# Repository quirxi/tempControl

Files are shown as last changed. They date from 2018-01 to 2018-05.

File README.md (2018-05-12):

# **Temperature Control**

A basic temperature control example that reads in a temperature via a K-Type thermocouple sensor.
The volt output of the sensor is processed by an MAX31855 board and read out by an Arduino Nano.
The so gained temperature value is given out to the serial console of the Arduino Nano.
On an output pin of the arduino nano a Solid State Relay (SSR) is connected. 
A PID controller is switching the SSR till the given target temperature is reached.

## Instructions

### What you need:

* [Thermocouple](https://www.banggood.com/de/Universal-K-Type-EGT-Thermocouple-Temperature-Sensors-For-Exhaust-Gas-Probe-p-1011377.html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)
* [MAX31855 K-Type thermoelement breakout board for arduino](https://www.banggood.com/de/MAX31855-K-Type-Thermocouple-Breakout-Board-Temperature-Measurement-Module-For-Arduino-p-1086523.html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)
* [Arduino Nano clone](https://www.banggood.com/de/ATmega328P-Arduino-Compatible-Nano-V3-Improved-Version-No-Cable-p-959231.html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)
* [Solid State Relay](https://www.banggood.com/80A-SSR-80DA-Solid-State-Relay-Module-DC-To-AC-24V-380V-Output-p-1097188.html)
* you will also need a soldering iron, jumper cables, breadbord etc.

### Setup

__Hardware__

1. Resolder the plug onto the other side of the MAX31855K breakout board, so that it can be easily attach it to the breadboard.

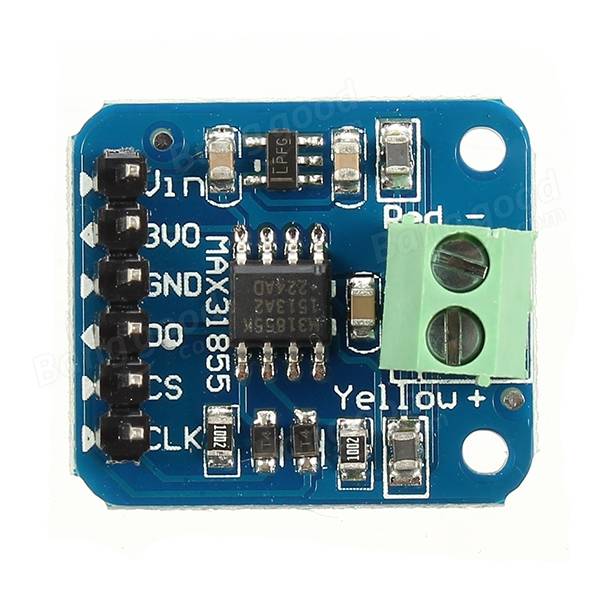
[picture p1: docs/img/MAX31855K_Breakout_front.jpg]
Original MAX31855K breakout board front

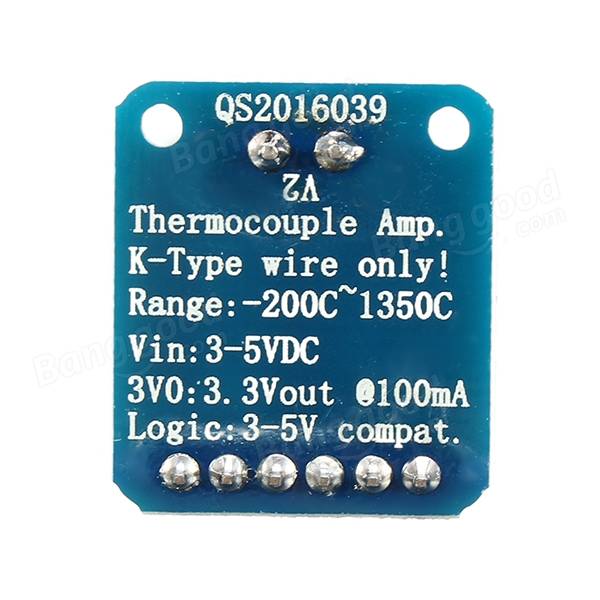
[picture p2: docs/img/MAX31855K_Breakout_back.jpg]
Original MAX31855K breakout board back

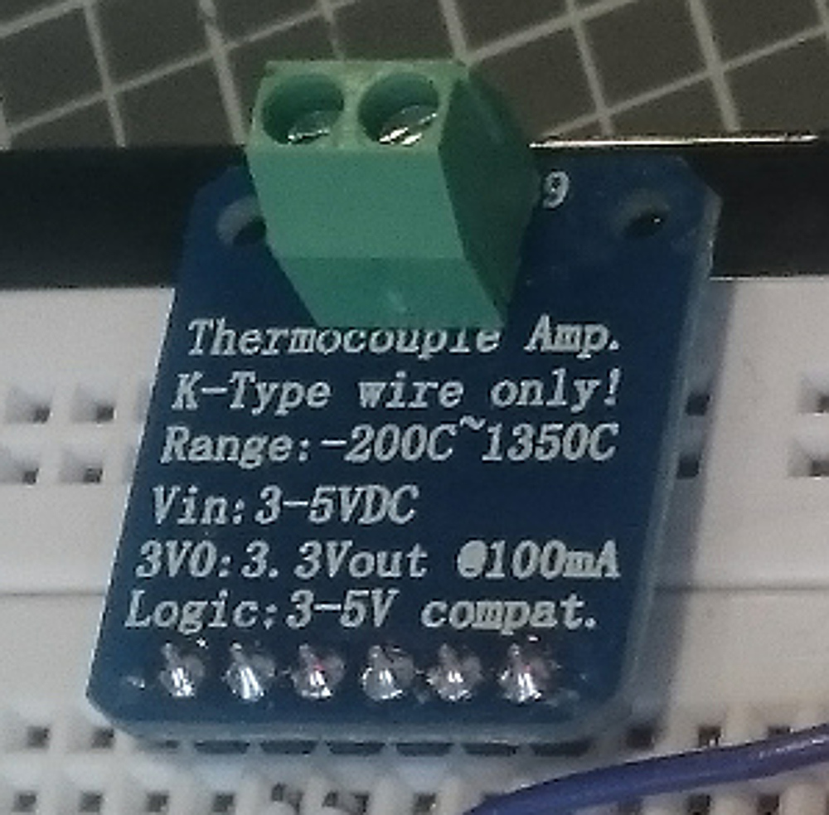
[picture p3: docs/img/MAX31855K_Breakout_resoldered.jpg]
MAX31855K breakout board resoldered


2. Connect the Arduino nano with the MAX31855K breakout board according to following circuit diagram.

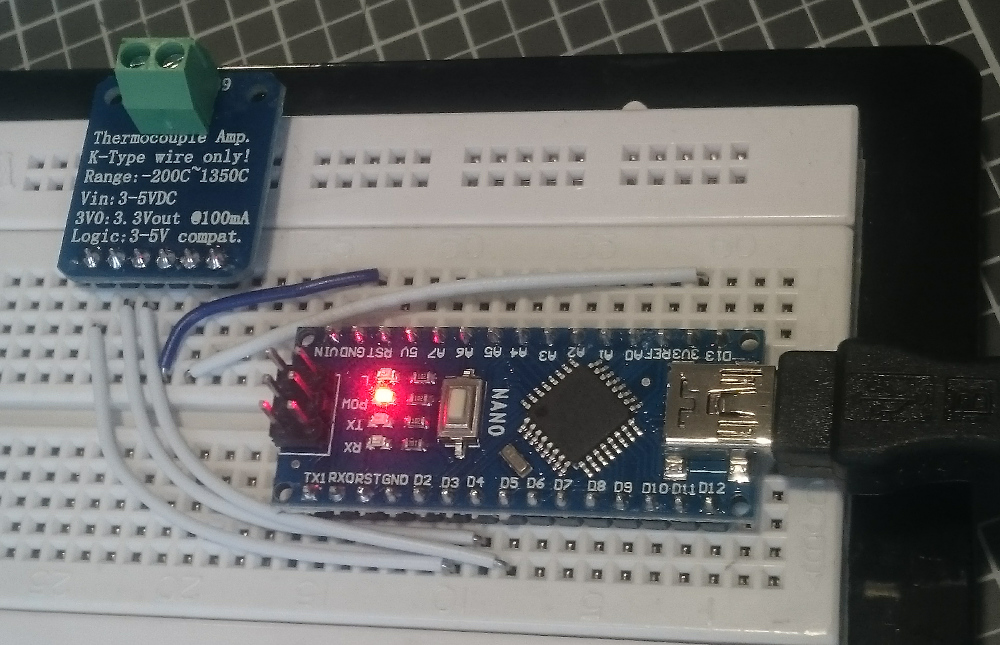
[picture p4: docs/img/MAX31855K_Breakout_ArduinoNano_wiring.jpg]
Breadboard wiring

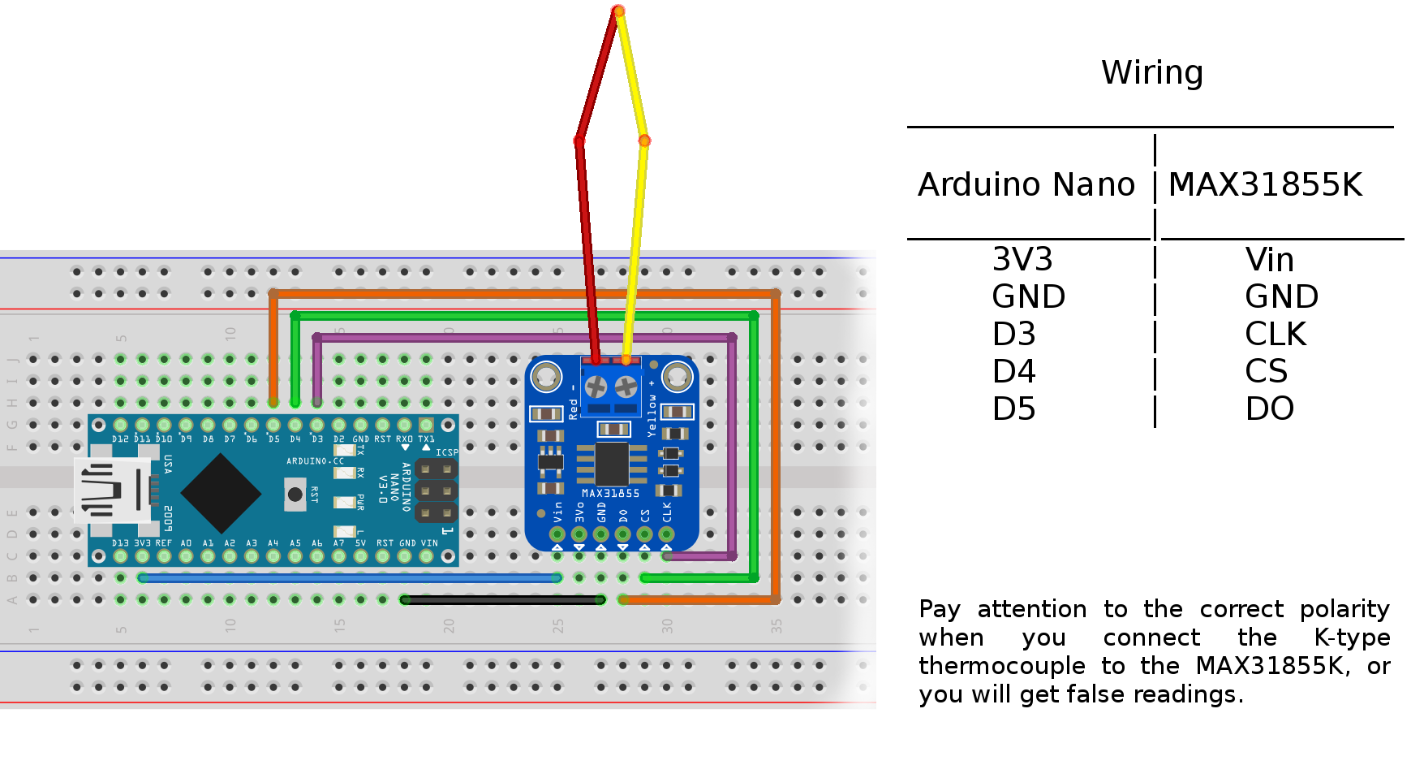
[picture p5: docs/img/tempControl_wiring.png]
Wiring diagram


* You can find the Fritzing wiring diagram file (tempControl.fzz) in the docs folder.

__Software__

1. Download and install the newest Arduino IDE from https://www.arduino.cc/en/Main/Software. 

2. If you need help using Arduino have a look at www.arduino.cc/en/Guide/HomePage. 
    
3. Install the newest Arduino IDE from https://www.arduino.cc/en/main/software (version 1.8.5 at time of writing). 
    
4. Open "Menu->Sketch->Include Libraries->Manage Libraries.." in the Arduino IDE and search for "Adafruit MAX31855" and "PID" by Brett Beauregard (version 1.2.0 at time of writing) and install it. 

### Programming

1. Open the "tempControl.ino" file that you can find here, "Verify" and "Upload" it to your Arduino board via USB connection
    
2. Once the code upload finishes verifying, open the serial monitor (found in the ‘Tools’ menu). You should be able to read the temperature your thermocouple is detecting on the serial monitor in real time. If it isn’t working, make sure you have assembled the circuit and uploaded the code to your board correctly. 

### Explanation

__1. K Type Thermocouple__

A thermocouple is a kind of temperature sensor, simply made by welding together two metal wires. Because of a physical effect of two joined metals, there is a slight but measurable voltage across the wires that increases with temperature (Seebeck-Effekt). The main advantage of using a thermocouple is the high temperature range (our K type: -200°C to 1200°C). A difficulty in using them is that the voltage to be measured is very small, with changes of about 50 uV per °C. To solve this we are using a thermocouple interface chip (MAX31855K) to measure the voltage between the wires. If you find that the thermocouple temperature goes down instead of up when heated, when connecting the K type thermocouples with the MAX31855K, try swapping the red and yellow wires.

__2. MAX31855K__

The MAX31855K is a chip that converts the voltage output of the thermocouple to a digital temperature value that is read out via SPI 
protocol. The first assembly step is creating a reliable, electrical connection from the MAX31855K breakout board to your Arduino. We chose 
to use a breakout board because we wanted to connect it to a bread board. The hookup is fairly straightforward. Connect the Arduino, MAX31855K and thermocouple as described in the Fritzing wiring diagram.

__3. Arduino nano__

The Arduino nano communicates with the MAX31855K through SPI protocol. For further details see next point.

__4. SPI protocol__

The SPI is a fast synchronous protocol that tipically uses uses 4 pins for communication, wiz. MISO, MOSI, SCK, and SS. These pins are directly related to the SPI bus interface.

    1. MISO – MISO stands for Master In Slave Out. MISO is the input pin for Master AVR, and output pin for Slave AVR device. Data transfer from Slave to Master takes place through this channel.
    2. MOSI – MOSI stands for Master Out Slave In. This pin is the output pin for Master and input pin for Slave. Data transfer from Master to Slave takes place through this channel.
    3. SCK – This is the SPI clock line (since SPI is a synchronous communication).
    4. SS – This stands for Slave Select. This pin would be discussed in detail later in the post.
    
__5. PID controller__

PID Controller is a most common control algorithm used in industrial automation & applications. PID controllers are used for precise and accurate control of various parameters. Most often these are used for the regulation of temperature, pressure, speed, flow and other process variables. For in depth information about how PID controller work see reference section.

## License

Distributed under the GNU LGPL v.3.0.

## References

* [Thermocouple](https://www.banggood.com/de/Universal-K-Type-EGT-Thermocouple-Temperature-Sensors-For-Exhaust-Gas-Probe-p-1011377.html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)
* [MAX31855 K-Type thermoelement breakout board for arduino](https://www.banggood.com/de/MAX31855-K-Type-Thermocouple-Breakout-Board-Temperature-Measurement-Module-For-Arduino-p-1086523.html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)
* [Arduino Nano clone](https://www.banggood.com/de/ATmega328P-Arduino-Compatible-Nano-V3-Improved-Version-No-Cable-p-959231.html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)
* [Solid State Relay](https://www.banggood.com/80A-SSR-80DA-Solid-State-Relay-Module-DC-To-AC-24V-380V-Output-p-1097188.html)
* [henrysbench arduino-max31855 tutorial](http://henrysbench.capnfatz.com/henrys-bench/arduino-temperature-measurements/max31855-arduino-k-thermocouple-sensor-manual-and-tutorial/)
* [MAX31855 specs and datasheet](https://datasheets.maximintegrated.com/en/ds/MAX31855.pdf)
* [ATmega328 Datasheet](http://www.atmel.com/Images/Atmel-42735-8-bit-AVR-Microcontroller-ATmega328-328P_Datasheet.pdf)
* [Arduino Nano Pinout Diagram](http://www.pighixxx.com/test/wp-content/uploads/2014/11/nano.png)
* [Arduino Anleitung](www.arduino.cc/en/Guide/HomePage)
* [K-Type Thermocouple specs](https://www.thermocoupleinfo.com/type-k-thermocouple.htm)
* [PID diagrams](http://ww1.microchip.com/downloads/en/AppNotes/Atmel-2558-Discrete-PID-Controller-on-tinyAVR-and-megaAVR_ApplicationNote_AVR221.pdf)
* [Working of a PID controller](https://www.elprocus.com/the-working-of-a-pid-controller/)
* [PID controller](http://manuals.chudov.com/Servo-Tuning/PID-without-a-PhD.pdf)
* [PID controlling algorithm](http://brettbeauregard.com/blog/2011/04/improving-the-beginners-pid-introduction/)
* [PID Arduino library](https://github.com/br3ttb/Arduino-PID-Library)
* [PID for dummies](https://www.csimn.com/CSI_pages/PIDforDummies.html)

## TODOs

* Solid State Relais
* GUI
* [PID tuning](https://en.wikipedia.org/wiki/Ziegler%E2%80%93Nichols_method)
* Change Fritzing pictures and table for hardware SPI.
* Pictures of new setpup with water kettle

## Authors

* quirxi (https://github.com/quirxi)
* Cubemast3r (https://github.com/Cubemast3r)

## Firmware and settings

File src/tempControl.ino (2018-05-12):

/*
   This program uses interrupts for (longer) timing tasks in the seconds range.

   @see: http://brettbeauregard.com/blog/2011/04/improving-the-beginner%e2%80%99s-pid-sample-time/
   @see: https://arduino-projekte.webnode.at/registerprogrammierung/timer-interrupt/
   @see: http://www.gammon.com.au/interrupts
   @see: http://www.gammon.com.au/timers
   @see: http://www.instructables.com/id/Arduino-Timer-Interrupts/
   @see: http://maxembedded.com/2011/07/avr-timers-ctc-mode/
 * */
////////////////////////////////////////////////////////////////////////////////////////////
// MAX31855 k-type thermocouple:
//                creating a thermocouple instance with hardware SPI on a given CS pin.
////////////////////////////////////////////////////////////////////////////////////////////
#include "Adafruit_MAX31855.h"
#define MAXCS   10
Adafruit_MAX31855 thermocouple(MAXCS);

////////////////////////////////////////////////////////////////////////////////////////////
// PID
////////////////////////////////////////////////////////////////////////////////////////////
#include "PIDcontrol.h"

// set the pins for input, output and sample frequency here:
const unsigned short PID_INPUT_PIN = 0; // pin from which sensor input is read
const unsigned short PID_RELAY_PIN = 5; // pin that is used to control relay

// specify the PID constants here:
double cProportional = 1000;            // the proportional constant
double cIntegral = 0;                   // the integral constant
double cDerivative = 0;                 // the derivative constant

double pidSetpoint;                     // the desired target setpoint
volatile double pidInput;               // the input to the PID controller as read from the sensor (=PID_INPUT_PIN)
volatile double pidLastInput;           // the last input to be remembered in case the current reading is NAN (Not a Number) and cannot be used for computation.
volatile double pidOutput;              // specifies how long the relay is switched on within a fixed period of time (=sampleInterval)
unsigned short  sampleInterval;         // a fixed period of time that determines a full PID on/off cycle (ms) ATTENTION: sampleInterval [ms] is the same as INTERRUPT_INTERVAL[s] and cannot be greater than 4.1944 seconds
volatile bool   errorReading;           // is set when temperature reading returned NAN
// initialize the PID controller
PIDcontrol myPID(&pidInput, &pidOutput, &pidSetpoint, cProportional, cIntegral, cDerivative, DIRECT);

////////////////////////////////////////////////////////////////////////////////////////////
// INTERRUPT
////////////////////////////////////////////////////////////////////////////////////////////

// ATTENTION: Here TIMER 1 is used which is a 16-bit timer. Thus the compare value cannot be greater than 65535, otherwise the timer would overflow.
//            So the maximum time between two interrupts with a cpu frequency of 16000000 hz can only be:
//                OCR1A = CMP_VALUE = INTERRUPT_INTERVAL * TICKS_PER_SEC - 1
//                => INTERRUPT_INTERVAL = CMP_VALUE / (TICKS_PER_SEC - 1)
//                => INTERRUPT_INTERVAL = CMP_VALUE / (( CPU_FREQ / PRESCALER ) - 1)
//                => INTERRUPT_INTERVAL = 65535 / (( 16000000 / 1024 ) - 1)
//                => INTERRUPT_INTERVAL = 4.1945 seconds

#define CPU_FREQ 16000000L    // cpu clock from boards.txt
#define PRESCALER 1024        // cpu prescaler

// NOTE: we use seconds here as a basis because when using miliseconds the precision of the number would be inexact due to floating point calculations.
const unsigned short TICKS_PER_SEC = ( CPU_FREQ / PRESCALER );            // base for calculation of compare value for output compare register OCR1A
const unsigned short INTERRUPT_INTERVAL = 4;                              // interrupt every 4 seconds (=maximum interrupt intervall and maximum sample pid sample time)
const unsigned short CMP_VALUE = INTERRUPT_INTERVAL * TICKS_PER_SEC - 1;  // compare value for OCR1A: = amount of ticks in an interrupt intervall
const unsigned short MAX_CMP_VALUE = 65535 - 1;                           // maximum number in a 16-bit variable

volatile unsigned long counter = 0;
volatile unsigned long cntCmp = 0;

////////////////////////////////////////////////////////////////////////////////////////////
// SETUP
////////////////////////////////////////////////////////////////////////////////////////////
void setup()
{
    // MAX31555 thermocouple and serial initialization
    Serial.begin(9600);
    while (!Serial) delay(1);           // wait for serial on Leonardo/Zero, etc
    delay(500);                         // wait for MAX chip to stabilize
    // SSR initialization
    pinMode(PID_RELAY_PIN, OUTPUT);     // set the relay pin to output
    digitalWrite(PID_RELAY_PIN, LOW);   // initialize relay pin to low
    //PID
    pinMode(PID_RELAY_PIN, OUTPUT);              // set the relay pin to output
    digitalWrite(PID_RELAY_PIN, LOW);            // initialize relay pin to low
    pidSetpoint = 55;                            // set the desired target value
    sampleInterval = INTERRUPT_INTERVAL * 1000;  // the sample time of the pid controller is the interrupt frequency in miliseconds
    myPID.SetSampleTime(sampleInterval);         // tell the PID controller how frequently we will read a sample and calculate output
    myPID.SetOutputLimits(0, sampleInterval);    // tell the PID to range between 0 and the full window size
    myPID.SetMode(AUTOMATIC);                    // turn the PID on
    pidInput = thermocouple.readCelsius();       // read temperature sensor input
    myPID.Compute();                             // compute pidOutput for the first time

    Serial.print("CPU_FREQ:            ");
    Serial.println(CPU_FREQ);
    Serial.print("PRESCALER:           ");
    Serial.println(PRESCALER);
    Serial.print("TICKS_PER_SEC:       ");
    Serial.println(TICKS_PER_SEC);
    Serial.print("CMP_VALUE:           ");
    Serial.println(CMP_VALUE);
    Serial.print("MAX_CMP_VALUE:       ");
    Serial.println(MAX_CMP_VALUE);
    Serial.print("INTERRUPT_INTERVAL: ");
    Serial.println(INTERRUPT_INTERVAL);

    Serial.print("sampleInterval: ");
    Serial.print(sampleInterval);
    Serial.print(" | Setpoint: ");
    Serial.print(pidSetpoint);
    Serial.print(" | P: ");
    Serial.print(cProportional);
    Serial.print(" I: ");
    Serial.print(cIntegral);
    Serial.print(" D: ");
    Serial.println(cDerivative);

    // INTERRUPTS
    cli();                               // disable global interrupts
    TCNT1 = 0;                           // delete timer counter register
    TCCR1A = 0;                          // delete TCCR1A-Registers
    TCCR1B = 0;                          // delete TCCR1B-Registers
    TCCR1B |= (1 << WGM12);              // CTC-Mode (Waveform Generation Mode): resets TCNT1 to0 after interrupt, makes OCR1A the leading compare register
    TCCR1B |= (1 << CS12) | (1 << CS10); // set prescaler to 1024: CS10 und CS12 (Clock Select)
    OCR1A = CMP_VALUE;                   // set compare value
    OCR1B = MAX_CMP_VALUE;               // a second comapare value in OCR1B can be used as long as its value is *lower* than that of OCR1A: here its higher so it wont be called in the beginning
    TIMSK1 |= (1 << OCIE1A) | (1 << OCIE1B); // enable interrupts: set output compare interrupt enable for 1A and 1B
    sei();                               // enable global interrupts
}

////////////////////////////////////////////////////////////////////////////////////////////
// INTERRUPTS
////////////////////////////////////////////////////////////////////////////////////////////
ISR(TIMER1_COMPA_vect)   // Interrupt Service Routine for timer 1 OCR1A
{
    pidInput = thermocouple.readCelsius(); // read temperature sensor input
    if (!isnan(pidInput)) pidLastInput = pidInput;
    else
    {
        pidInput = pidLastInput;
        errorReading = true;
    }
    myPID.Compute();                       // compute pidOutput

    if (pidOutput > 0)
        digitalWrite(PID_RELAY_PIN, HIGH);
    else
        digitalWrite(PID_RELAY_PIN, LOW);

    // trigger interrupt b to turn off relay within the sample time (=sampleInterval)
    if ( pidOutput > 0 && pidOutput < sampleInterval )
        OCR1B = ((pidOutput * TICKS_PER_SEC) / 1000) - 1;
    else
        OCR1B = MAX_CMP_VALUE;    // we set OCR1B higher than OCR1A so that the second b interrupt never gets called

    ++counter;                    // flag that signals the start of a new cycle to the main loop
}

// Interrupt Service Routine for timer 1 OCR1B
ISR(TIMER1_COMPB_vect)
{
    digitalWrite(PID_RELAY_PIN, LOW);
}

////////////////////////////////////////////////////////////////////////////////////////////
// MAIN LOOP
////////////////////////////////////////////////////////////////////////////////////////////
void loop()
{
    if (cntCmp != counter)    // use != for comparison and not < because it could give problems when unsigned long overflows
    {
        Serial.print(counter);
        Serial.print(": ");
        Serial.print(millis());
        if (errorReading)   // for error codes see: https://cdn-shop.adafruit.com/datasheets/MAX31855.pdf#page=10 
        {
            Serial.print(":\tERROR: ");
            uint8_t errorCode = thermocouple.readError();
            switch( errorCode )
            {
            case 1:
                Serial.println("(1) Thermocouple has no connection (open circuit)!");
                break;
            case 2:
                Serial.println("(2) Thermocouple short-circuited to GND!");
                break;
            case 4:
                Serial.println("(4) Thermocouple short-circuited to VCC!");
                break;
            default:
                Serial.print("(");
                Serial.print(errorCode);
                Serial.println(") Unkown error code!");
            }
            errorReading=false;    // IMPORTANT: reset error flag !!
        }
        else
        {
            Serial.print(":\tpidInput: ");
            Serial.print( pidInput);
            Serial.print(" | pidOutput: ");
            Serial.print(pidOutput);
            Serial.print(" | OCR1A: ");
            Serial.print(OCR1A);
            Serial.print(" | OCR1B: ");
            Serial.println(OCR1B);
        }
        cntCmp = counter;
    }
}

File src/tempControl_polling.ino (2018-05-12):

#include "Adafruit_MAX31855.h"
#include <PID_v1.h>

// @TODO: Error handling when readCelsius returns NAN

// set the pins for input, output and sample frequency here:
//const unsigned short PID_INPUT_PIN = 0; // pin from which sensor input is read
const unsigned short PID_RELAY_PIN = 5; // pin that is used to control relay
const unsigned int PID_CYCLE = 4000;    // a fixed period of time that determines a full PID on/off cycle (ms)

// specify the PID constants here:
double cProportional = 1000;          // the proportional constant
double cIntegral = 0;                 // the integral constant
double cDerivative = 0;               // the derivative constant

double pidSetpoint;                     // the desired target setpoint
double pidInput;                        // the input to the PID controller as read from the sensor (=PID_INPUT_PIN)
double pidOutput;                       // specifies how long the relay is switched on within a fixed period of time (=PID_CYCLE)
unsigned long pidStart;                 // variable that marks the start of each PID_CYCLE
// initialize the PID controller
PID myPID(&pidInput, &pidOutput, &pidSetpoint, cProportional, cIntegral, cDerivative, DIRECT);


// creating a thermocouple instance with hardware SPI on a given CS pin.
#define MAXCS   10
Adafruit_MAX31855 thermocouple(MAXCS);


////////////////////////////////////////////////////////////////////////////////
//
////////////////////////////////////////////////////////////////////////////////
void setup()
{
  // MAX31555 thermocouple and serial initialization
  Serial.begin(9600);
  while (!Serial) delay(1); // wait for serial on Leonardo/Zero, etc
  delay(500);  // wait for MAX chip to stabilize
  // PID and SSR initialization
  pinMode(PID_RELAY_PIN, OUTPUT);       // set the relay pin to output
  digitalWrite(PID_RELAY_PIN, LOW);     // initialize relay pin to low
  pidSetpoint = 50;                     // set the desired target value
  myPID.SetSampleTime(PID_CYCLE);       // tell the PID controller how frequently we will read a sample and calculate output
  myPID.SetOutputLimits(0, PID_CYCLE);  // tell the PID to range between 0 and the full window size
  myPID.SetMode(AUTOMATIC);             // turn the PID on
  pidStart = millis();                  // here our first pid cycle (=PID_CYCLE) starts
  pidInput = thermocouple.readCelsius();// read sensor input
  myPID.Compute();                      // compute pidOutput for the first time
  Serial.print("\nPid Cycle: "); Serial.print(PID_CYCLE); Serial.print(" | Setpoint: "); Serial.print(pidSetpoint); Serial.print(" | P: "); Serial.print(cProportional); Serial.print(" I: "); Serial.print(cIntegral); Serial.print(" D: "); Serial.println(cDerivative);
}
////////////////////////////////////////////////////////////////////////////////
//
////////////////////////////////////////////////////////////////////////////////
void loop()
{
  // compute pidOutput each PID_CYCLE
  if (millis() - pidStart >= PID_CYCLE)
  {
    pidStart = millis();                    // reset pidStart to begin of new PID_CYCLE
    pidInput = thermocouple.readCelsius();  // read sensor input
    // compute pidOutput
    if (!myPID.Compute()) Serial.println("Error in compute()!!");
    Serial.print(pidStart); Serial.print("\tTemperature C: "); Serial.print( pidInput); Serial.print(" | pidOutput: "); Serial.println(pidOutput);
    if (pidOutput > 0)
    {
      digitalWrite(PID_RELAY_PIN, HIGH);
      if (pidOutput < PID_CYCLE)            // only switch off relay when necessary, otherwise leave it on till next PID_CYCLE starts
      {
        delay(pidOutput);
        digitalWrite(PID_RELAY_PIN, LOW);
      }
    }
    else digitalWrite(PID_RELAY_PIN, LOW);  // set relay pin low when pidOutput = 0
  }
}

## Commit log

2017-11-24 Added link to MAX31855 K-Type thermoelement breakout board for arduino.
2017-11-30 Added links to the Adafruit MAX 31855 library and the SPI library on github.
2017-11-30 Added link to Arduino Nano pinout diagram.
2018-01-26 Added Fritzing circuit diagram.
    [tempControl.fzz]
2018-01-26 Added wiring diagram.
2018-01-26 Added picture of wiring diagram.
2018-03-09 Removed include SPI.h because it is already included in the Adafruit library.
2018-03-09 Finished Setup section, Explanation of K Type Thermocouple, MAX31855K, SPI protocol and edited programming section.
2018-03-16 Added information about PID controller.
2018-05-08 Switched from software to hardware spi and fixed all bugs concerning output hanling. Code was tested and works.
    [tempControl.ino]
2018-05-11 Changed the wiring diagram.
    [tempControl.fzz]
2018-05-12 Added files that implement interrupt driven PID control.
